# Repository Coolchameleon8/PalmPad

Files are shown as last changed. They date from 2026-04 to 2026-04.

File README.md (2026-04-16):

PalmPad
A single handed keyboard based on the hackclub hackpad. Uses a resistor ladder and custom qmk firmware to allow for more inputs than the seeduino xiao has room for.
This is still a work in progress and the case is just temporary. The final version will look similar to a joystick. It is however difficult to design the joystick without the pcb as it has to be broken into parts. This document will be updated later on.

Prototype of the palmpad, just used to test electronics and clearances.
Onshape Link:
https://cad.onshape.com/documents/9e26ee7e9571adbf7a7901c8/w/e33cc611a5f829e6b25b9a69/e/7c23ee493dd5f25881813654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


Wiring schematic for the palmpad


The PCB design



How the case fits together



BOM:
*Seeeduino xiao rp2040
*16x SK6812 MINI-E LEDs
*2x EC11 Rotary encoders
*14x MX-Style switches
*10x through-hole 1N4148 Diodes
*1x 0.91 inch OLED display
*14x white blank DSA keycaps
*4x M3x16mm screws

NOT in hackpad kit
*Assorted wire
*6 10nF smd 1206 capacitors
*6 1k Ohm smd 1206 capacitors
*7 200k Ohm smd 1206 capacitors
*5 100k Ohm smd 1206 capacitors

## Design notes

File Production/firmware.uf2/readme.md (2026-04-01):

# palmpadv1

palmpadv1

*A short description of the keyboard/project*

* Keyboard Maintainer: [Damian Marcinek](https://github.com/Coolchameleon8)
* Hardware Supported: *The PCBs, controllers supported*
* Hardware Availability: *Links to where you can find this hardware*

Make example for this keyboard (after setting up your build environment):

    make palmpadv1:default

Flashing example for this keyboard:

    make palmpadv1:default:flash

See the [build environment setup](https://docs.qmk.fm/#/getting_started_build_tools) and the [make instructions](https://docs.qmk.fm/#/getting_started_make_guide) for more information. Brand new to QMK? Start with our [Complete Newbs Guide](https://docs.qmk.fm/#/newbs).

## Bootloader

Enter the bootloader in 3 ways:

* **Bootmagic reset**: Hold down the key at (0,0) in the matrix (usually the top left key or Escape) and plug in the keyboard
* **Physical reset button**: Briefly press the button on the back of the PCB - some may have pads you must short instead
* **Keycode in layout**: Press the key mapped to `QK_BOOT` if it is available

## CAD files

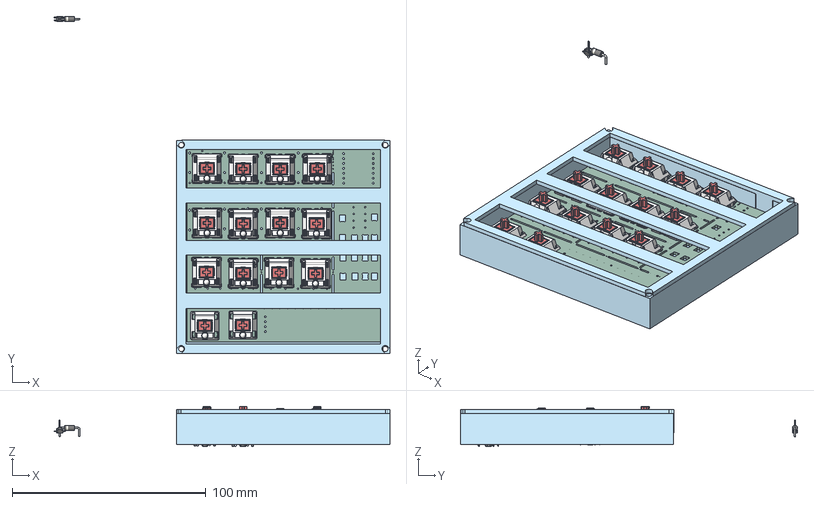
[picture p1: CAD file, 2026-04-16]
CAD/Full Case with PCB.step
173.2 x 173.9 x 20.8 mm
Pin1 x 15
Pieza5^Cherry MX x 14
Led 3mm_trans x 28
Pin2 x 15
Pulsador x 14
Bottom x 14
palmpadpcb_PCB
Top x 14
R_1206_3216Metric
Pin3
D_DO-41_SOD81_P10.16mm_Horizontal
PinHeader_1x01_P2.00mm_Vertical
C_1206_3216Metric
Pin4

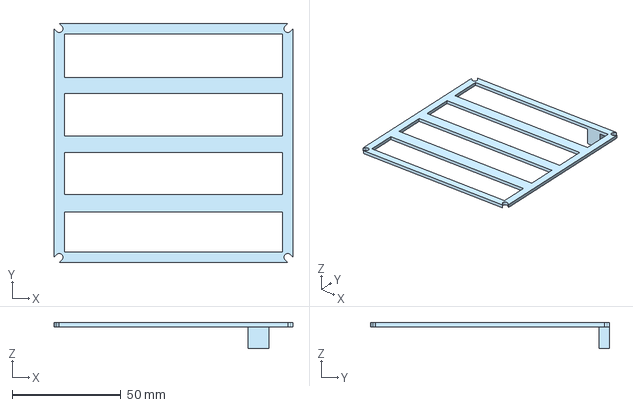
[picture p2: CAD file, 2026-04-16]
CAD/Top Cover.step
110.0 x 110.0 x 12.0 mm

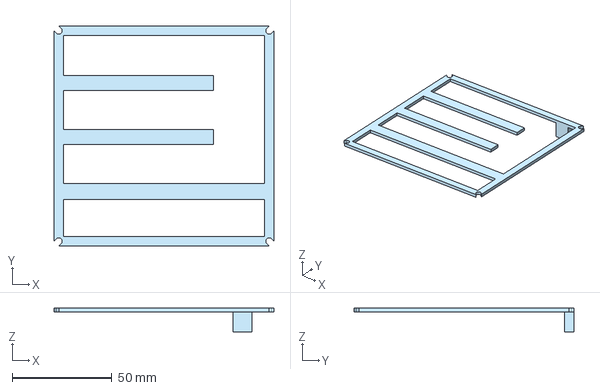
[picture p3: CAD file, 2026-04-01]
Production/Top Cover.step
110.0 x 110.0 x 12.0 mm

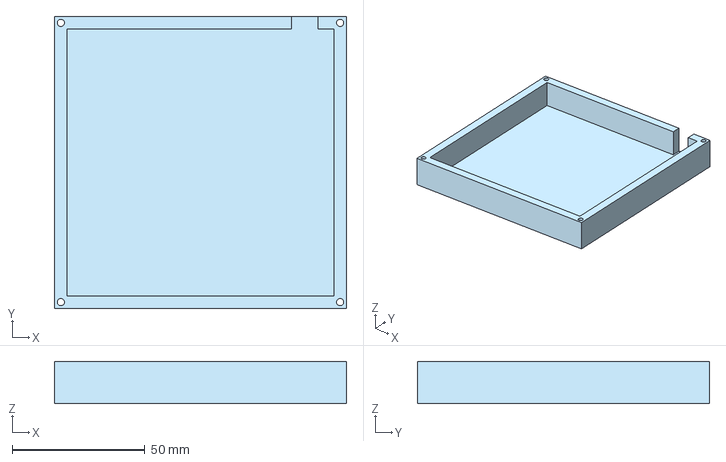
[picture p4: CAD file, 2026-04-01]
CAD/Bottom cover.step
110.0 x 110.0 x 16.0 mm

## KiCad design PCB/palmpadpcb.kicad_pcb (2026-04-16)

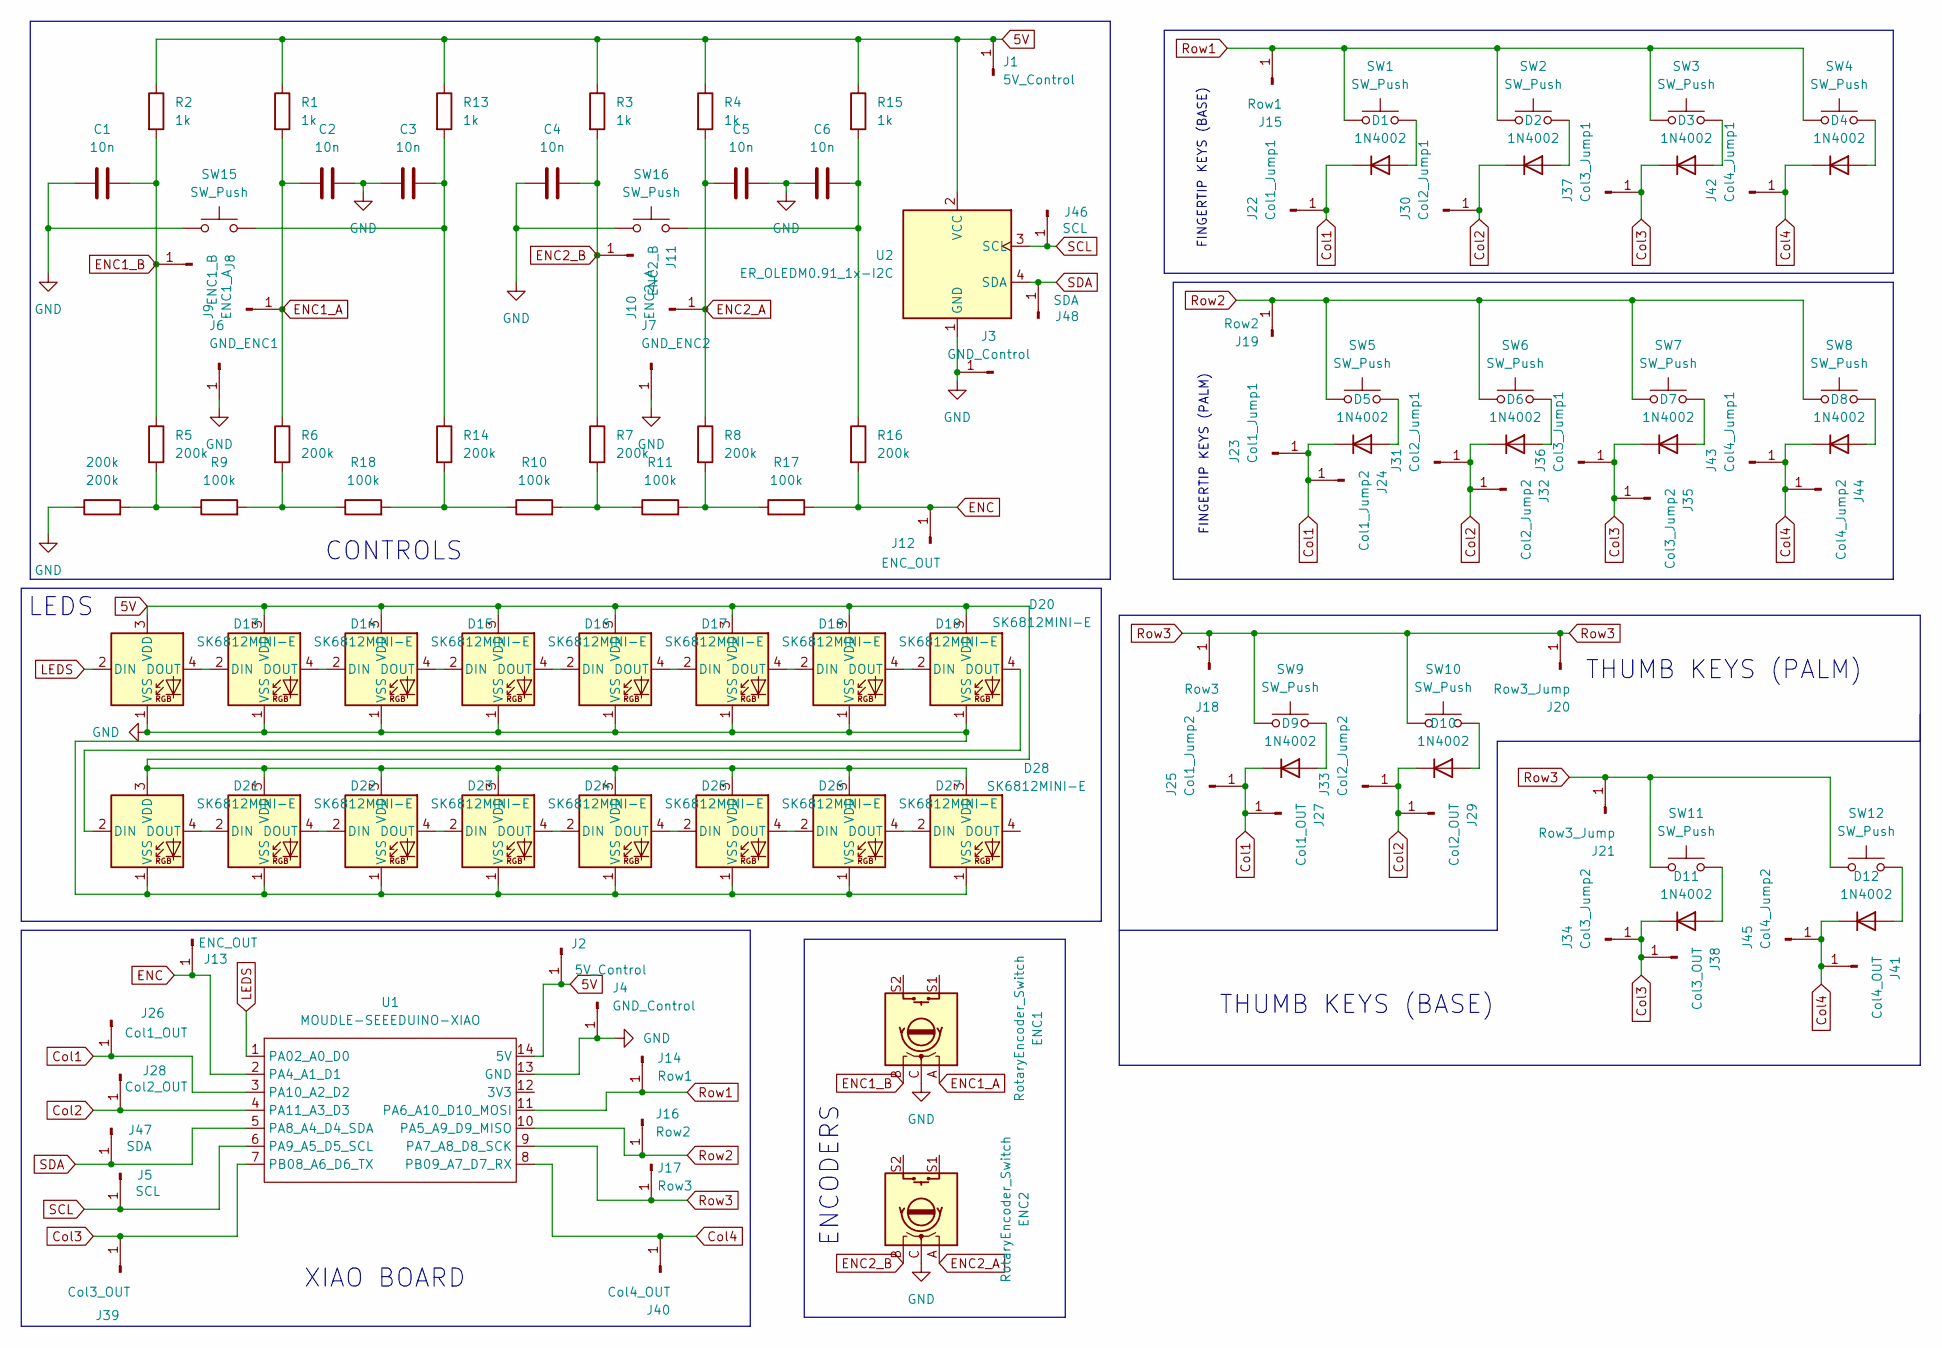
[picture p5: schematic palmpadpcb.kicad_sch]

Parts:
200k: 200k; R_Axial_DIN0207_L6.3mm_D2.5mm_P10.16mm_Horizontal
C1, C2, C3, C4, C5, C6: 10n; CP_Axial_L10.0mm_D4.5mm_P15.00mm_Horizontal
D1, D2, D3, D4, D5, D6, D7, D8, D9, D10, D11, D12: 1N4002; D_DO-41_SOD81_P10.16mm_Horizontal
D13, D14, D15, D16, D17, D18, D19, D20, D21, D22, D23, D24, D25, D26, D27, D28: SK6812MINI-E; LED_SK6812MINI-E_3.2x2.8mm_P1.5mm_ReverseMount
ENC1, ENC2: RotaryEncoder_Switch; RotaryEncoder_Alps_EC11E-Switch_Vertical_H20mm
J1, J2: 5V_Control; PinHeader_1x01_P2.00mm_Vertical
J3, J4: GND_Control; PinHeader_1x01_P2.00mm_Vertical
J5, J46: SCL; PinHeader_1x01_P2.00mm_Vertical
J6: GND_ENC1; PinHeader_1x01_P2.00mm_Vertical
J7: GND_ENC2; PinHeader_1x01_P2.00mm_Vertical
J8: ENC1_B; PinHeader_1x01_P2.00mm_Vertical
J9: ENC1_A; PinHeader_1x01_P2.00mm_Vertical
J10: ENC2_A; PinHeader_1x01_P2.00mm_Vertical
J11: ENC2_B; PinHeader_1x01_P2.00mm_Vertical
J12, J13: ENC_OUT; PinHeader_1x01_P2.00mm_Vertical
J14, J15: Row1; PinHeader_1x01_P2.00mm_Vertical
J16, J19: Row2; PinHeader_1x01_P2.00mm_Vertical
J17, J18: Row3; PinHeader_1x01_P2.00mm_Vertical
J20, J21: Row3_Jump; PinHeader_1x01_P2.00mm_Vertical
J22, J23: Col1_Jump1; PinHeader_1x01_P2.00mm_Vertical
J24, J25: Col1_Jump2; PinHeader_1x01_P2.00mm_Vertical
J26, J27: Col1_OUT; PinHeader_1x01_P2.00mm_Vertical
J28, J29: Col2_OUT; PinHeader_1x01_P2.00mm_Vertical
J30, J31: Col2_Jump1; PinHeader_1x01_P2.00mm_Vertical
J32, J33: Col2_Jump2; PinHeader_1x01_P2.00mm_Vertical
J34, J35: Col3_Jump2; PinHeader_1x01_P2.00mm_Vertical
J36, J37: Col3_Jump1; PinHeader_1x01_P2.00mm_Vertical
J38, J39: Col3_OUT; PinHeader_1x01_P2.00mm_Vertical
J40, J41: Col4_OUT; PinHeader_1x01_P2.00mm_Vertical
J42, J43: Col4_Jump1; PinHeader_1x01_P2.00mm_Vertical
J44, J45: Col4_Jump2; PinHeader_1x01_P2.00mm_Vertical
J47, J48: SDA; PinHeader_1x01_P2.00mm_Vertical
R1, R2, R3, R4, R13, R15: 1k; R_Axial_DIN0207_L6.3mm_D2.5mm_P10.16mm_Horizontal
R5, R6, R7, R8, R14, R16: 200k; R_Axial_DIN0207_L6.3mm_D2.5mm_P10.16mm_Horizontal
R9, R10, R11, R17, R18: 100k; R_Axial_DIN0207_L6.3mm_D2.5mm_P10.16mm_Horizontal
SW1, SW2, SW3, SW4, SW5, SW6, SW7, SW8, SW9, SW10, SW11, SW12, SW15, SW16: SW_Push; SW_Cherry_MX_1.00u_PCB
U1: MOUDLE-SEEEDUINO-XIAO; XIAO-Generic-Hybrid-14P-2.54-21X17.8MM
U2: ER_OLEDM0.91_1x-I2C

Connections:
5V: D13.3 (VDD), D14.3 (VDD), D15.3 (VDD), D16.3 (VDD), D17.3 (VDD), D18.3 (VDD), D19.3 (VDD), D20.3 (VDD), D21.3 (VDD), D22.3 (VDD), D23.3 (VDD), D24.3 (VDD), D25.3 (VDD), D26.3 (VDD), D27.3 (VDD), D28.3 (VDD), J1.1 (Pin_1_1), J2.1 (Pin_1_1), R1.1, R2.1, R3.1, R4.1, R13.1, R15.1, U1.14 (5V), U2.2 (VCC)
Col1: D1.1 (K), D5.1 (K), D9.1 (K), J22.1 (Pin_1_1), J23.1 (Pin_1_1), J24.1 (Pin_1_1), J25.1 (Pin_1_1), J26.1 (Pin_1_1), J27.1 (Pin_1_1), U1.3 (PA10_A2_D2)
Col2: D2.1 (K), D6.1 (K), D10.1 (K), J28.1 (Pin_1_1), J29.1 (Pin_1_1), J30.1 (Pin_1_1), J31.1 (Pin_1_1), J32.1 (Pin_1_1), J33.1 (Pin_1_1), U1.4 (PA11_A3_D3)
Col3: D3.1 (K), D7.1 (K), D11.1 (K), J34.1 (Pin_1_1), J35.1 (Pin_1_1), J36.1 (Pin_1_1), J37.1 (Pin_1_1), J38.1 (Pin_1_1), J39.1 (Pin_1_1), U1.7 (PB08_A6_D6_TX)
Col4: D4.1 (K), D8.1 (K), D12.1 (K), J40.1 (Pin_1_1), J41.1 (Pin_1_1), J42.1 (Pin_1_1), J43.1 (Pin_1_1), J44.1 (Pin_1_1), J45.1 (Pin_1_1), U1.8 (PB09_A7_D7_RX)
ENC: J12.1 (Pin_1_1), J13.1 (Pin_1_1), R16.2, R17.2, U1.2 (PA4_A1_D1)
ENC1_A: C2.1, ENC1.A, J9.1 (Pin_1_1), R1.2, R6.1
ENC1_B: C1.2, ENC1.B, J8.1 (Pin_1_1), R2.2, R5.1
ENC2_A: C5.1, ENC2.A, J10.1 (Pin_1_1), R4.2, R8.1
ENC2_B: C4.2, ENC2.B, J11.1 (Pin_1_1), R3.2, R7.1
GND: 200k.1, C1.1, C2.2, C3.1, C4.1, C5.2, C6.1, D13.1 (VSS), D14.1 (VSS), D15.1 (VSS), D16.1 (VSS), D17.1 (VSS), D18.1 (VSS), D19.1 (VSS), D20.1 (VSS), D21.1 (VSS), D22.1 (VSS), D23.1 (VSS), D24.1 (VSS), D25.1 (VSS), D26.1 (VSS), D27.1 (VSS), D28.1 (VSS), ENC1.C, ENC2.C, J3.1 (Pin_1_1), J4.1 (Pin_1_1), J6.1 (Pin_1_1), J7.1 (Pin_1_1), SW15.1, SW16.1, U1.13 (GND), U2.1 (GND); also elsewhere on the board
LEDS: D13.2 (DIN), U1.1 (PA02_A0_D0)
unnamed: C3.2, R13.2, R14.1, SW15.2
unnamed: C6.2, R15.2, R16.1, SW16.2
unnamed: D1.2 (A), SW1.2
unnamed: D2.2 (A), SW2.2
unnamed: D3.2 (A), SW3.2
unnamed: D4.2 (A), SW4.2
unnamed: D5.2 (A), SW5.2
unnamed: D6.2 (A), SW6.2
unnamed: D7.2 (A), SW7.2
unnamed: D8.2 (A), SW8.2
unnamed: D9.2 (A), SW9.2
unnamed: D10.2 (A), SW10.2
unnamed: D11.2 (A), SW11.2
unnamed: D12.2 (A), SW12.2
unnamed: D13.4 (DOUT), D14.2 (DIN)
unnamed: D14.4 (DOUT), D15.2 (DIN)
unnamed: D15.4 (DOUT), D16.2 (DIN)
unnamed: D16.4 (DOUT), D17.2 (DIN)
unnamed: D17.4 (DOUT), D18.2 (DIN)
unnamed: D18.4 (DOUT), D19.2 (DIN)
unnamed: D19.4 (DOUT), D20.2 (DIN)
unnamed: D20.4 (DOUT), D21.2 (DIN)
unnamed: D21.4 (DOUT), D22.2 (DIN)
unnamed: D22.4 (DOUT), D23.2 (DIN)
unnamed: D23.4 (DOUT), D24.2 (DIN)
unnamed: D24.4 (DOUT), D25.2 (DIN)
unnamed: D25.4 (DOUT), D26.2 (DIN)
unnamed: D26.4 (DOUT), D27.2 (DIN)
unnamed: D27.4 (DOUT), D28.2 (DIN)
unnamed: R10.1, R14.2, R18.2
unnamed: R7.2, R10.2, R11.1
unnamed: R8.2, R11.2, R17.1
unnamed 44: 200k.2, R5.2, R9.1; also elsewhere on the board
unnamed: R6.2, R9.2, R18.1
Row1: J14.1 (Pin_1_1), J15.1 (Pin_1_1), SW1.1, SW2.1, SW3.1, SW4.1, U1.11 (PA6_A10_D10_MOSI)
Row2: J16.1 (Pin_1_1), J19.1 (Pin_1_1), SW5.1, SW6.1, SW7.1, SW8.1, U1.10 (PA5_A9_D9_MISO)
Row3: J17.1 (Pin_1_1), J18.1 (Pin_1_1), J20.1 (Pin_1_1), J21.1 (Pin_1_1), SW9.1, SW10.1, SW11.1, SW12.1, U1.9 (PA7_A8_D8_SCK)
SCL: J5.1 (Pin_1_1), J46.1 (Pin_1_1), U1.6 (PA9_A5_D5_SCL), U2.3 (SCL)
SDA: J47.1 (Pin_1_1), J48.1 (Pin_1_1), U1.5 (PA8_A4_D4_SDA), U2.4 (SDA)

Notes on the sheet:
CONTROLS
THUMB KEYS (BASE)
FINGERTIP KEYS (PALM)
FINGERTIP KEYS (BASE)
ENCODERS
LEDS
THUMB KEYS (PALM)
XIAO BOARD

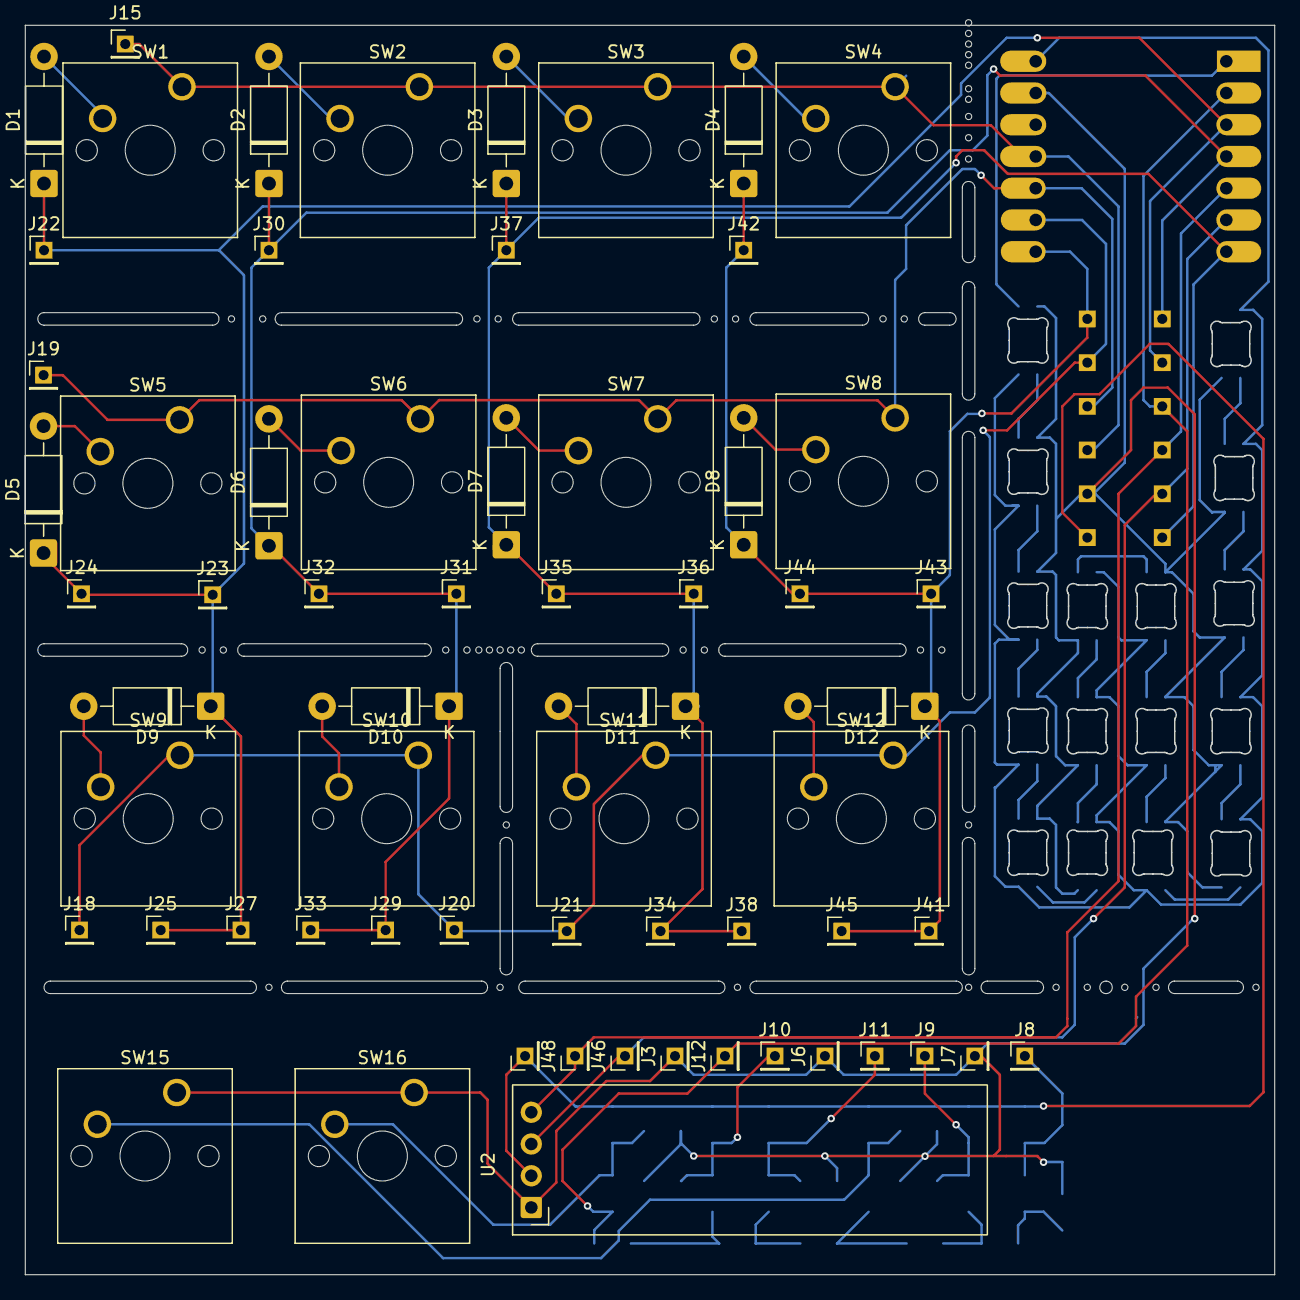
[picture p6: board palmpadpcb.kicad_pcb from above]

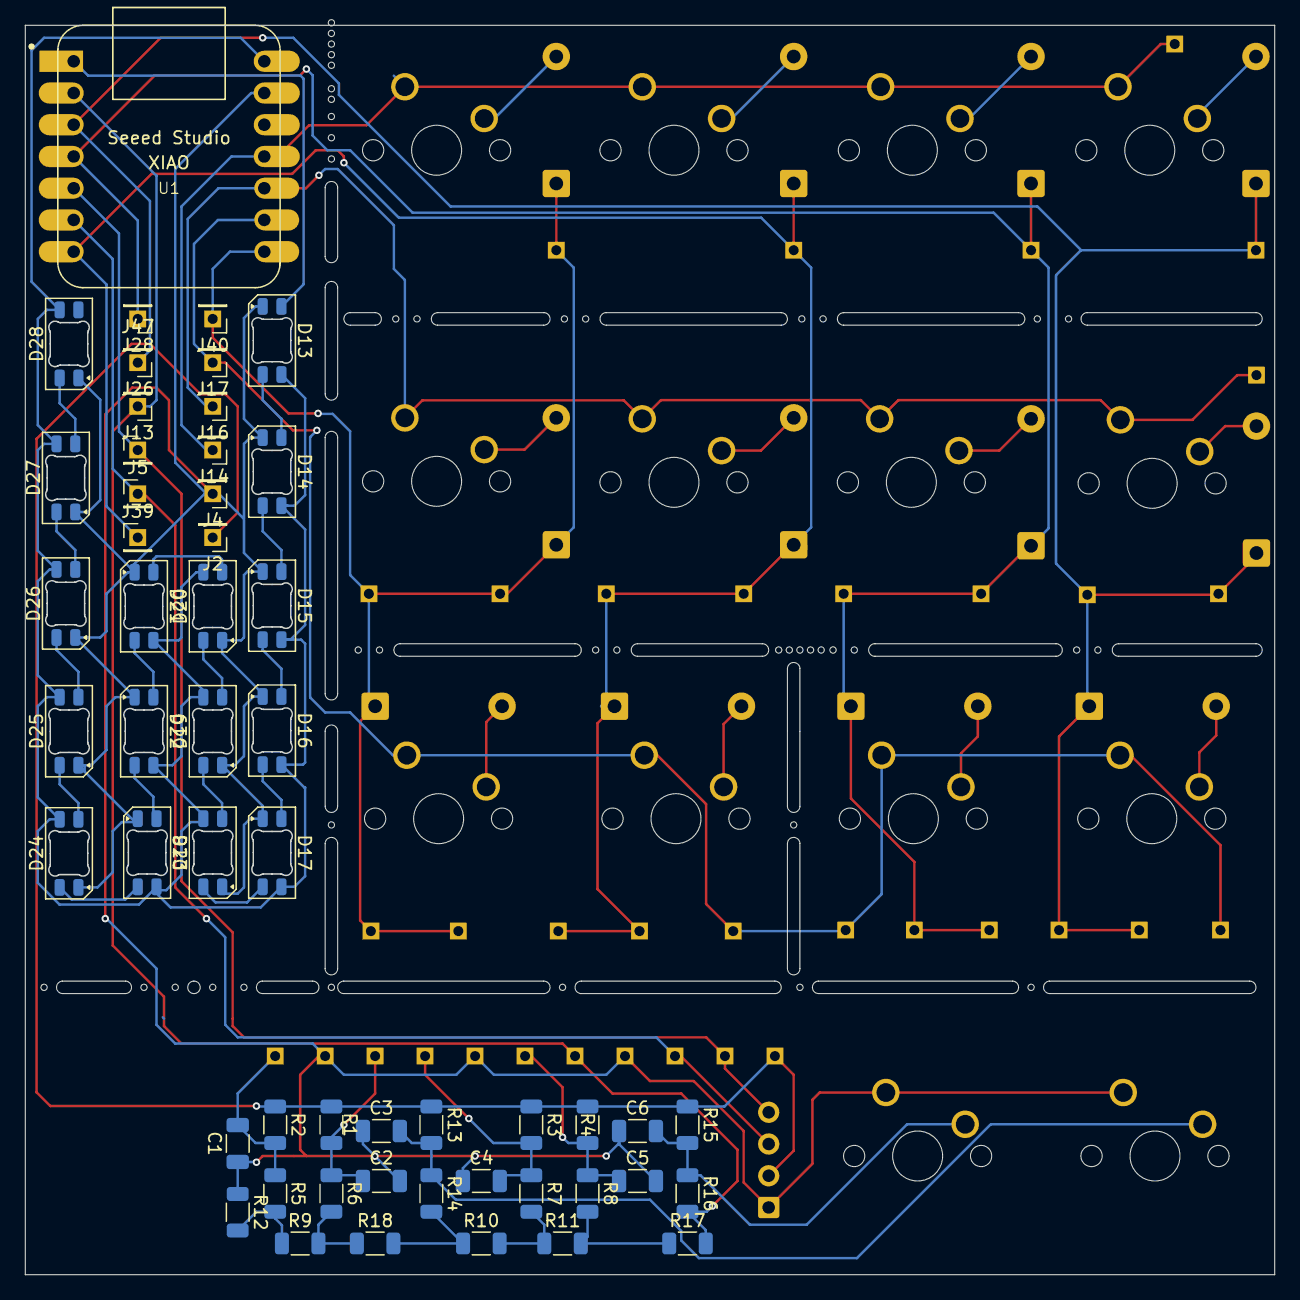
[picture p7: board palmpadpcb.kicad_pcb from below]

Board: 2 copper layers, 100.0 x 100.0 mm, 116 parts (53 on the bottom side), 51 nets.

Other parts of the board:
R12: 200k; R_1206_3216Metric

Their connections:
GND: R12.1; also elsewhere on the board
unnamed 44: R12.2; also elsewhere on the board

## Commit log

2026-04-01 Palmpad prototype 1 without firmware
    [Bottom cover.step, Palmpad Proto 1.step, Top Cover.step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]
2026-04-16 Revision 2
    [Bottom cover.step, Full Case with PCB.step, Palmpad Proto 1.step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]
